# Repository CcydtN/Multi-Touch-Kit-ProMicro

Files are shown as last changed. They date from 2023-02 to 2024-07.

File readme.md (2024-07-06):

# Multi-Touch-Kit-ProMicro

As the title suggests, this project is trying to reproduce the result of [Multi-Touch kit](https://hci.cs.uni-saarland.de/projects/multi-touch-kit/) with a ProMicro board.

---
## Demo
https://user-images.githubusercontent.com/51289140/219960157-e1035877-1ed2-4f21-ac63-bcd13f59a0d3.mp4
> The demo is using the source code from "experiment" branch (See Note.2)

> The two axis in the demo is a mess, but I am not planning to fixed it in short term.
---
## Preparation
In this repo:
- A python script to create the grid
- A KiCad project for the pcb design
- The source code for the ProMicro
- Clone of [Multi-Touch Kit Processing code](https://github.com/HCI-Lab-Saarland/MultiTouchKitUI)

Not in the repo:
- [PlatformIO](https://platformio.org/)
- [Processing](https://processing.org/)

---
## Procedure
Most steps is following the Multi-Touch Kit Project
1. Create a schemetic
2. Print out the PCB and prepare the components
3. Connect all pins and wires
4. Upload the code through PlatformIO
5. Use Processing to observe the result

---
## Note
1. Readings from R1 seem having a lot of noise and effecting the result, so it is disabled.
2. "Experiment" branch seem to have a better performance. I am trying to figure out the reason, feel free to comment in the [issue](https://github.com/CcydtN/Multi-Touch-Kit-ProMicro/issues/2).

---
Reference:
- [Multi-Touch Kit](https://hci.cs.uni-saarland.de/projects/multi-touch-kit/)
    - The Starting point of this project
- [Sensor Design Guidelines](http://ww1.microchip.com/downloads/en/DeviceDoc/FAQs%20-%20Sensor%20Design%20Guidelines.pdf)
    - More detail about pcb design can be found here.
    - The python script for generating grid is base on this document.
- [Pro Micro & Fio V3 Hookup Guide](https://learn.sparkfun.com/tutorials/pro-micro--fio-v3-hookup-guide/hardware-overview-pro-micro)
    - Pin layout about ProMicro

---
## Future Plan
- [ ] Learn about USB-HID
  - https://www.usb.org/hid
  - https://docs.kernel.org/hid/index.html
  - https://learn.microsoft.com/en-us/windows-hardware/design/component-guidelines/touchpad-sample-report-descriptors
  - https://github.com/smulikHakipod/USB-Emulation/tree/master

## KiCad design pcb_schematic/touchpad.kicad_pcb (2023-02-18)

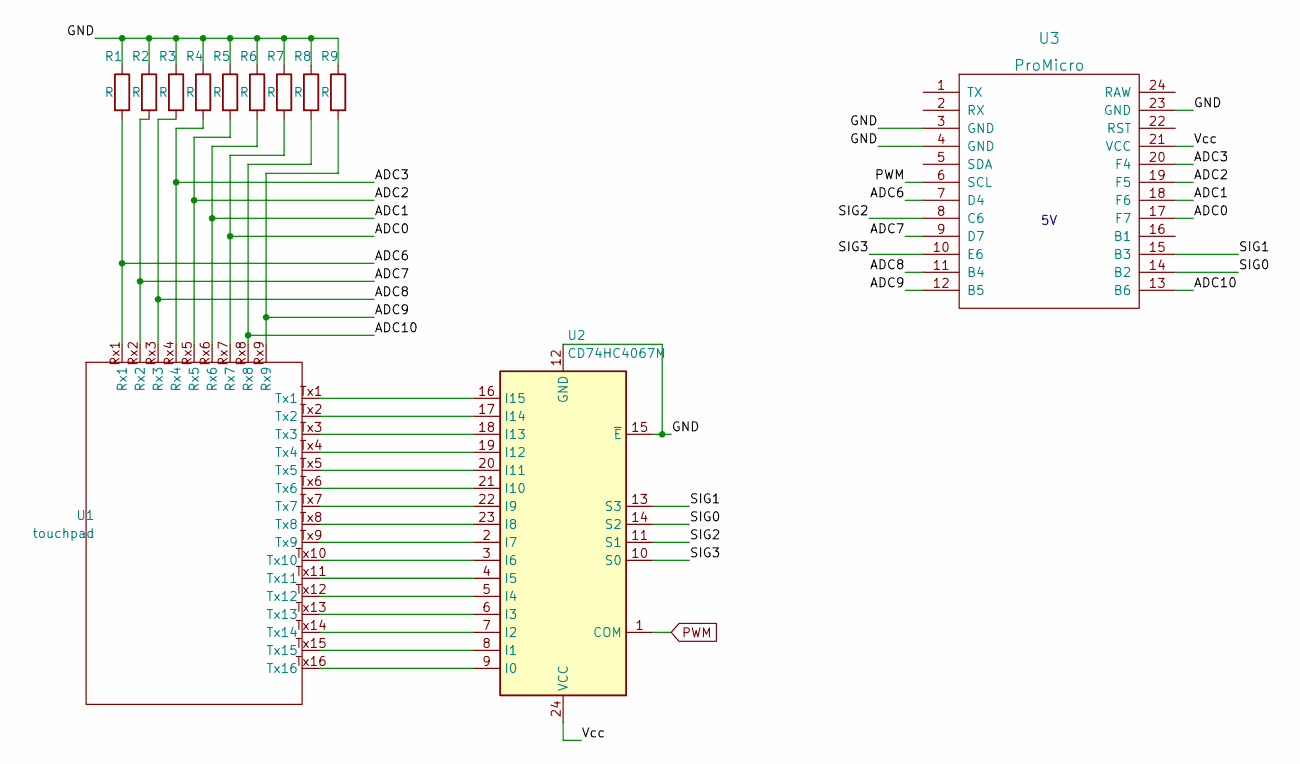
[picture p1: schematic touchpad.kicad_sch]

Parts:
R1, R2, R3, R4, R5, R6, R7, R8, R9: R; R_0805_2012Metric
U1: touchpad
U2: CD74HC4067M; SOIC-24W_7.5x15.4mm_P1.27mm
U3: ProMicro

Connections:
/ADC0: R7.2, U1.Rx7, U3.17 (F7)
/ADC1: R6.2, U1.Rx6, U3.18 (F6)
/ADC2: R5.2, U1.Rx5, U3.19 (F5)
/ADC3: R4.2, U1.Rx4, U3.20 (F4)
/ADC6: R1.2, U1.Rx1, U3.7 (D4)
/ADC7: R2.2, U1.Rx2, U3.9 (D7)
/ADC8: R3.2, U1.Rx3, U3.11 (B4)
/ADC9: R9.2, U1.Rx9, U3.12 (B5)
/ADC10: R8.2, U1.Rx8, U3.13 (B6)
/GND: R1.1, R2.1, R3.1, R4.1, R5.1, R6.1, R7.1, R8.1, R9.1, U2.12 (GND), U2.15 (~E), U3.3 (GND), U3.4 (GND), U3.23 (GND)
/SIG0: U2.14 (S2), U3.14 (B2)
/SIG1: U2.13 (S3), U3.15 (B3)
/SIG2: U2.11 (S1), U3.8 (C6)
/SIG3: U2.10 (S0), U3.10 (E6)
/Vcc: U2.24 (VCC), U3.21 (VCC)
unnamed: U1.Tx1, U2.16 (I15)
unnamed: U1.Tx2, U2.17 (I14)
unnamed: U1.Tx3, U2.18 (I13)
unnamed: U1.Tx4, U2.19 (I12)
unnamed: U1.Tx5, U2.20 (I11)
unnamed: U1.Tx6, U2.21 (I10)
unnamed: U1.Tx7, U2.22 (I9)
unnamed: U1.Tx8, U2.23 (I8)
unnamed: U1.Tx9, U2.2 (I7)
unnamed: U1.Tx10, U2.3 (I6)
unnamed: U1.Tx11, U2.4 (I5)
unnamed: U1.Tx12, U2.5 (I4)
unnamed: U1.Tx13, U2.6 (I3)
unnamed: U1.Tx14, U2.7 (I2)
unnamed: U1.Tx15, U2.8 (I1)
unnamed: U1.Tx16, U2.9 (I0)
PWM: U2.1 (COM), U3.6 (SCL)

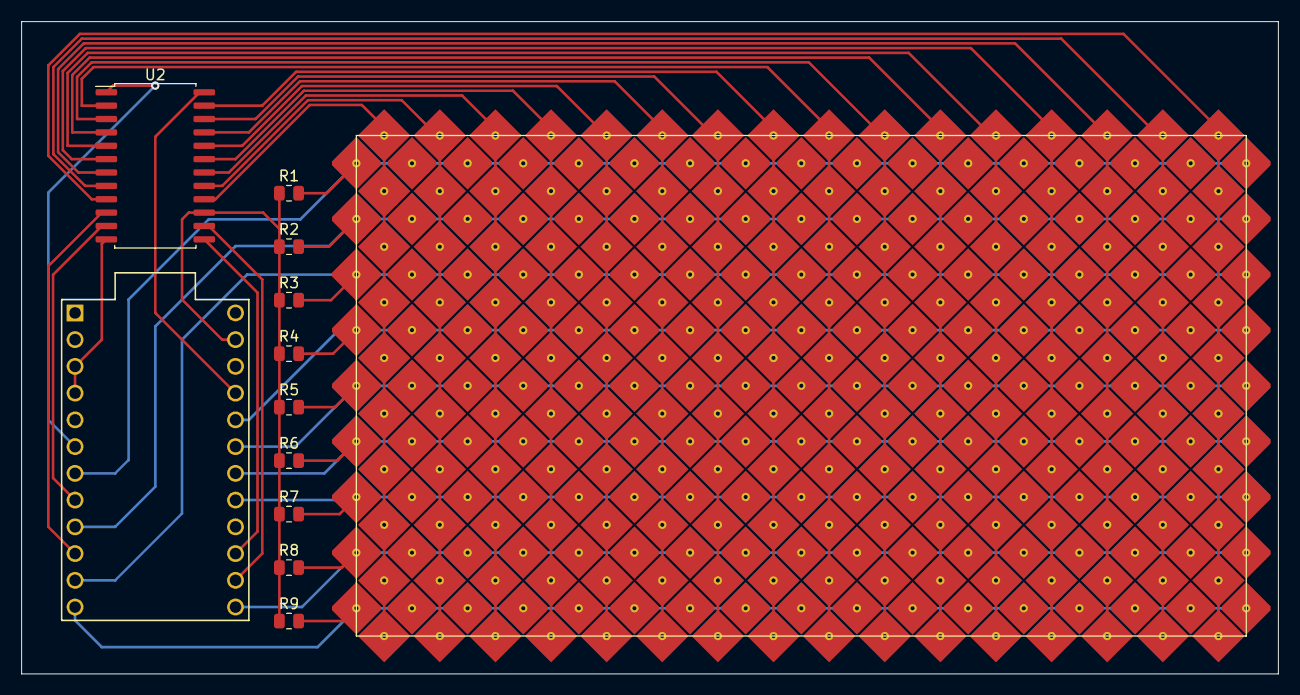
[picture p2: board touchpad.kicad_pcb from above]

Board: 2 copper layers, 119.4 x 62.0 mm, 12 parts (0 on the bottom side), 32 nets.

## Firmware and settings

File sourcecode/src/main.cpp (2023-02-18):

#include <Arduino.h>

constexpr uint8_t TX = 3;
constexpr uint8_t TX_MUX[] = { 7, 5, 16, 14 }; // S0 -> S3
constexpr uint8_t RX[] = { /*4,*/ 6, 8, 21, 20, 19, 18, 10, 9};

uint8_t mask = 0b0001;
uint8_t channel = 0;

void select_pwm_channel(const uint8_t& channel){
  mask = 0b0001;
  for (const auto& pin: TX_MUX){
    digitalWrite(pin, static_cast<uint8_t>((channel & mask)==0));
    mask <<= 1;
  }
}

void setup() {
  Serial.begin(0);
  for (const auto& pin: TX_MUX){ pinMode(pin, OUTPUT); }
  for (const auto& pin: RX){ pinMode(pin, INPUT); }

  pinMode(TX,OUTPUT);
  TCCR0A = (COM0A0) | _BV(COM0B1) | _BV(WGM01) | _BV(WGM00);
  TCCR0B = _BV(WGM02) | _BV(CS00);
  OCR0A = 3;
  OCR0B = 1;
  // analogReference(INTERNAL);         //change reference to 1.1V
}

void loop() {
  for (channel = 0; channel < (1 << 4); ++channel){
    select_pwm_channel(channel);
    Serial.print(channel);
    for (const auto &pin : RX){
      Serial.print(",");
      Serial.print(analogRead(pin));
    }
    Serial.println();
  }
}

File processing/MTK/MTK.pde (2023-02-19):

/***************************************************
 This is a library for the Multi-Touch Kit
 Designed and tested to work with Arduino Uno, MEGA2560, LilyPad(ATmega 328P)
 
 For details on using this library see the tutorial at:
 ----> https://hci.cs.uni-saarland.de/multi-touch-kit/
 
 Written by Jan Dickmann, Narjes Pourjafarian, Juergen Steimle (Saarland University),
 Anusha Withana (University of Sydney), Joe Paradiso (MIT)
 MIT license, all text above must be included in any redistribution
 ****************************************************/


/*
This example shows how to use "Multi-Touch Kit Processing library" in your code.
With this code you can visualize the touch points and/or save the raw capacitive data in a CSV file.

You can change these two variables to get the optimum results:
"maxInputRange" : If the touch points are not bright enough, decrease this value.
"threshold"     : If the touch points are not detected as blobs, decrease this value.

Please insert the correct Index of Serial Port and number of RX and TX based on the size of the sensor
*/


import gab.opencv.*;
import MultiTouchKitUI.*;
import processing.serial.*;
import blobDetection.*;



int tx = 16;               //number of transmitter lines (rx)
int rx = 8;               //number of receiver lines (rx)
int serialPort = 0;       //serial port that the Arduino is connected to
Serial myPort;
MultiTouchKit mtk;

int maxInputRange = 40;  // set the brightness of touch points (blobs)
float threshold = 0.75f;  // set the threshold for blob detection

int[][] values;           // values used for visualization
int[][] rawvalues;        // raw values recieved from serial port
long[][] baseline;        // baseline values saved for calibartion

Table tableRaw;           // table for recording raw values 
Table tableAdj;           // table for recording values used for visualization
Table tableBas;           // table for recording baseline values 



void setup(){
  println(Serial.list());
  size(500,500);
  background(255);
  mtk = new MultiTouchKit(this,tx,rx,serialPort,500,500);      // instantiate the MultiTouchKit  
  mtk.autoDraw(true);                                          // visualize the touch points
  mtk.setMaxInputRange(maxInputRange);                         // set the brightness of touch points
  mtk.setThresh(threshold);                                    // set the threshold for blob detection
  
  
  // -------------- Uncomment this part, if you want to save the data in a CSV file --------------
  /*
  tableRaw = new Table(); 
  tableAdj = new Table(); 
  tableBas = new Table(); 
  
  tableRaw.addColumn("Tline");
  for(int i = 0; i<rx; i++){
    tableRaw.addColumn(Integer.toString(i));
  }
  tableAdj.addColumn("Tline");
  for(int i = 0; i<rx; i++){
    tableAdj.addColumn(Integer.toString(i));
  }
  tableBas.addColumn("Tline");
  for(int i = 0; i<rx; i++){
    tableBas.addColumn(Integer.toString(i));
  }
  */
  // --------------------------------------------------------------------------------------------
  
}

void draw(){
  
  values = mtk.getAdjustedValues();                            // values used for visualization
  rawvalues = mtk.getRawValues();                              // raw values recieved from serial port
  baseline = mtk.getBaseLine();                                // baseline values saved for calibartion
  
  // -------------- Uncomment this part, if you want to save the data in a CSV file --------------
  /*
  for(int i = 0; i < tx; i++){
    TableRow newRow = tableBas.addRow();
    newRow.setInt("Tline", i);
    for(int j = 0; j < rx; j++){
      newRow.setLong(Integer.toString(j),baseline[i][j]);
    }
  }
  
  for(int i = 0; i < tx; i++){
    TableRow newRow = tableRaw.addRow();
    newRow.setInt("Tline", i);
    for(int j = 0; j < rx; j++){
      newRow.setInt(Integer.toString(j),rawvalues[i][j]);
    }
  }


 for(int i = 0; i < tx; i++){
    TableRow newRow = tableAdj.addRow();
    newRow.setInt("Tline", i);
    for(int j = 0; j < rx; j++){
      newRow.setInt(Integer.toString(j),values[i][j]);
    }
  } 
  saveTable(tableRaw, "tableRaw.csv");
  saveTable(tableAdj, "tableAdj.csv");
  saveTable(tableBas, "tableBas.csv");
  */
  
  // ---------------------------------------------------------------------------------------------------------------------------

  // -------------- Uncomment this part, if you want to see the raw values, and calibrated values for debugging --------------

  println("values: ");
  for(int i = 0; i < tx; i++){
    print("tx "+i+" :");
    for(int j = 0; j < rx; j++){
      print(" "+values[i][j]);
    }
    println();
  }
  println("------------------------------------------");
  println("rawvalues: ");
  for(int i = 0; i < tx; i++){
    print("tx "+i+" :");
    for(int j = 0; j < rx; j++){
      print(" "+rawvalues[i][j]);
    }
    println();
  }
  println("------------------------------------------");
  //println("BaseLine: ");
  //for(int i = 0; i < tx; i++){
  //  print("tx "+i+" :");
  //  for(int j = 0; j < rx; j++){
  //    print(" "+baseline[i][j]);
  //  }
  //  println();
  //}
  //println("------------------------------------------");
  // ---------------------------------------------------------------------------------------------------------------------------
  
  
  
}

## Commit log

2023-02-18 First Commit!!!
    [touchpad.kicad_pcb, touchpad.kicad_sch]
2023-02-19 Fix PCB tag naming
    [touchpad.kicad_sch]
2023-02-19 Add the modified version of Processing Code, and some minor fix
    [MTK.pde]
